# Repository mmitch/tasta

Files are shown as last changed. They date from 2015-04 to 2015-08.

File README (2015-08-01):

tasta - small USB keyboard
Copyright (C) 2015 by  Christian Garbs <mitch@cgarbs.de>
Licensed under GNU GPL v2 or v3

Project homepage:
-----------------
https://github.com/mmitch/tasta

Description:
------------
tasta a small USB HID keyboard with just two keys and the
corresponding code to program the ATtiny85.  This is my first
microcontroller/PCB project.  I developed it as a foot switch for
push-to-talk in TeamSpeak as I don't have any spare keys (or fingers)
during gaming.  I fiddled with this on and off over the course of two
years, now it should be ready to do something.

Hardware:
---------
The curcuit schematics and PCB layout are available in different
formats in the 'circuit' subdirectory.  They were created with KiCad,
so it's propably best to edit them with KiCad, too, if the need
arises.

There are some optional components in the layout:

 - You can omit the LED and R5 if you don't need it.

 - You can omit either key switch or the K1 connector as needed.  K1
   is used to provide key input from 'offboard', like the foot switch
   I use.

 - R4 is propably not needed.  In fact, I have never included it,
   neither in test runs nor in the final PCB.  But the docs say you
   should pull up your reset pin, so the possibility to insert the
   resistor is there if you should ever need it.  (I did include it
   'just in case' so I would not have to throw away the first PCB
   batch.)

Software:
---------
To build the software, go to the 'source' directory and just run
'make'.  A normal Atmel development environment is needed, so install
'avr-gcc' and friends.

To configure the software (to choose your own keybindings), edit
'main.c' and look for these two sections:
 - EDIT BELOW FOR YOUR OWN LED CONFIGURATION
 - EDIT BELOW FOR YOUR OWN KEY CONFIGURATION

Default configuration is:
 - key 1 = GUI left (Windows key -> modifier only)
 - key 2 = return
 - the LED is on if key 1 || key 2 is pressed

To flash the code to your ATtiny85, run 'make flash'.  The default
configuration uses avrdude with a 'usbasp' compatible programmer.
Edit the AVRDUDE_* variables in 'Makefile.orig' to change this.

Credits:
--------
PCB and basic code are heavily influenced from other projects, as you
can see in the repository log.  Other parts were rewritten, redone and
rearranged by myself.  Credits where credits are due:

 * VUSB project for USB on Atmel microcontrollers:
   http://www.obdev.at/vusb/

 * VUSB HIDKeys example project for a USB HID compliant keyboard:
   https://www.obdev.at/products/vusb/hidkeys.html

 * Information on running a VUSB project without a crystal taken from
   flipwork's 1-Key-keyboard:
   http://blog.flipwork.nl/?x=entry:entry081009-142605

 * better OSCCAL calibration routine taken from here:
   http://codeandlife.com/2012/02/22/v-usb-with-attiny45-attiny85-without-a-crystal/

 * My PCBs were printed at Hackvana.  I've never done this before and
   everything went right on the first try (well, on the second, I had
   one misnamed file in the rev_0x0002 export, but that's my fault):
   http://www.hackvana.com/

Licensing:
----------
The VUSB example projects are licensed under GPL 2 or GPL 3 (you can
choose).  The imported code from flipwork and codeandlife is based on
VUSB projects as well (HIDKeys/EasyLogger), so they're GPL 2/3, too.
My project thus is also GPL 2/3 and everybody's happy.

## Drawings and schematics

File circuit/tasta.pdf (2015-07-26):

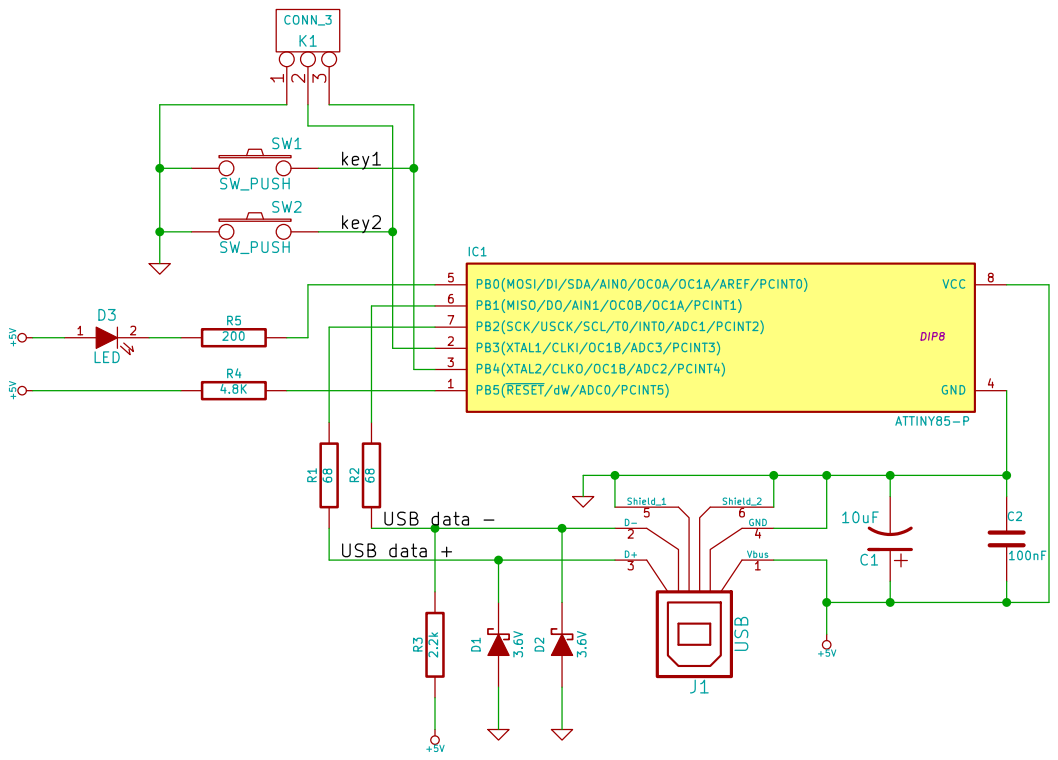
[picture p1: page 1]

https://github.com/mmitch/tasta
http://www.cgarbs.de/
Christian Garbs <mitch@cgarbs.de>
Id: 1/1 Title: tasta File: tasta.sch Sheet: /

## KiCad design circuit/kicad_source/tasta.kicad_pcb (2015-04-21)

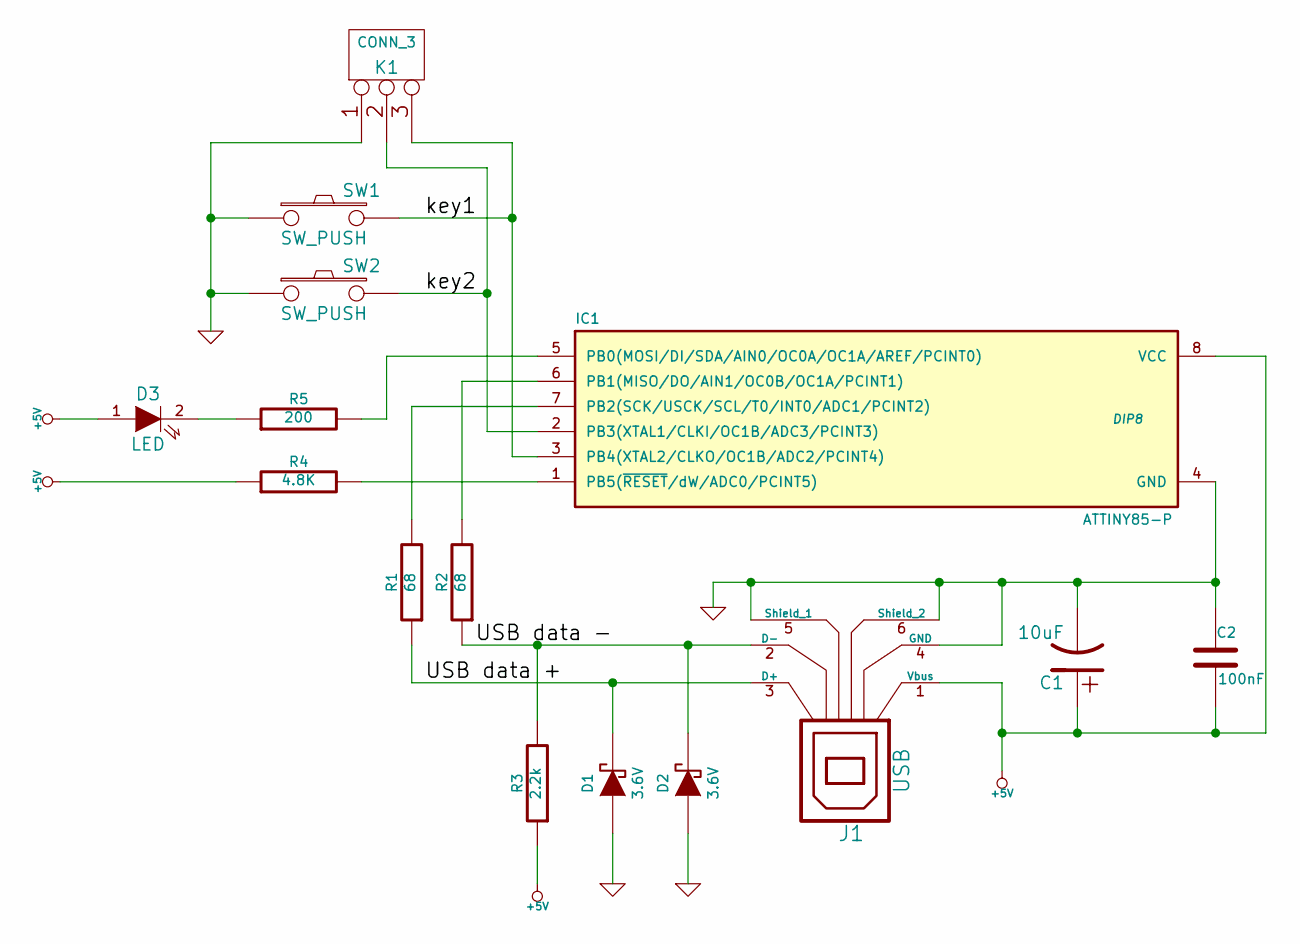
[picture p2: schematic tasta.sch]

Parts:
C1: 10uF
C2: 100nF
D1, D2: 3.6V
D3: LED
IC1: ATTINY85-P; DIP8
J1: USB
K1: CONN_3
R1, R2: 68
R3: 2.2k
R4: 4.8K
R5: 200
SW1, SW2: SW_PUSH

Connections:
+5V: C1.1, C2.2, D3.1 (A), IC1.8 (VCC), J1.1 (Vbus), R3.1, R4.1
/USB data +: D1.2 (K), J1.3 (D+), R1.1
/USB data -: D2.2 (K), J1.2 (D-), R2.1, R3.2
/key1: IC1.3 (PB4(XTAL2/CLKO/OC1B/ADC2/PCINT4)), K1.3, SW1.2
/key2: IC1.2 (PB3(XTAL1/CLKI/OC1B/ADC3/PCINT3)), K1.2 (PM), SW2.2
GND: C1.2, C2.1, D1.1 (A), D2.1 (A), IC1.4 (GND), J1.4 (GND), J1.5 (Shield_1), J1.6 (Shield_2), K1.1, SW1.1, SW2.1
unnamed: IC1.6 (PB1(MISO/DO/AIN1/OC0B/OC1A/PCINT1)), R2.2
unnamed: D3.2 (K), R5.1
unnamed: IC1.7 (PB2(SCK/USCK/SCL/T0/INT0/ADC1/PCINT2)), R1.2
unnamed: IC1.5 (PB0(MOSI/DI/SDA/AIN0/OC0A/OC1A/AREF/PCI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), R5.2
unnamed: IC1.1 (PB5(~RESET~/dW/ADC0/PCINT5)), R4.2

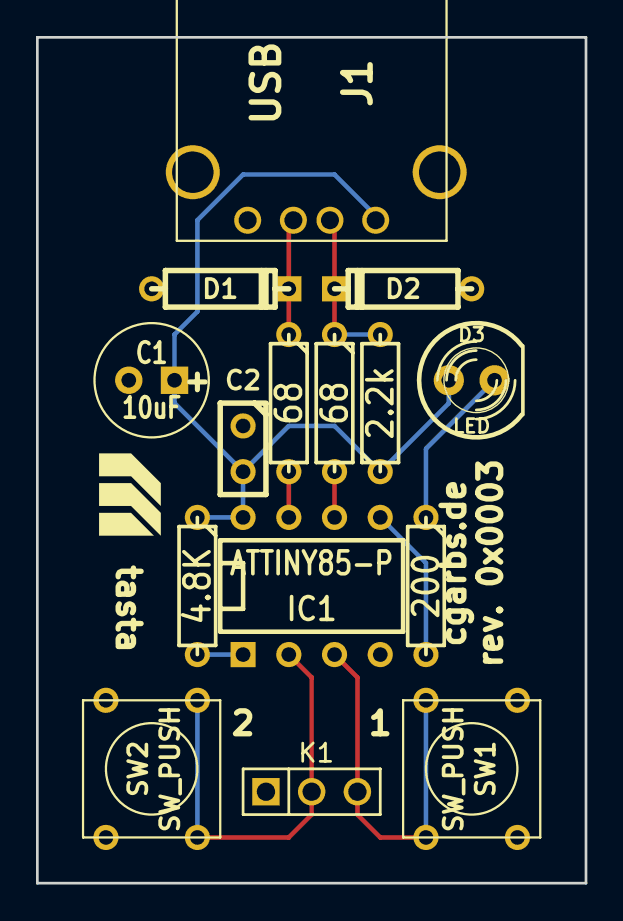
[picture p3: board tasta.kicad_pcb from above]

Board: 2 copper layers, 30.5 x 47.0 mm, 15 parts (0 on the bottom side), 11 nets.

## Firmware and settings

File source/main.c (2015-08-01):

/*
 * tasta - simple USB keyboard for ATtiny85
 * Copyright (C) 2015 Christian Garbs <mitch@cgarbs.de>
 * Licensed under GNU GPL v2 or v3
 *
 * based upon HIDKeys example from V-USB/obdev:
 *
 *
 * Name: main.c
 * Project: HID-Test
 * Author: Christian Starkjohann
 * Creation Date: 2006-02-02
 * Copyright: (c) 2006 by OBJECTIVE DEVELOPMENT Software GmbH
 * License: GNU GPL v2  (or GNU GPL v3 as the complete License.txt says)
 * Homepage: http://www.obdev.at/vusb/
 * Source: https://www.obdev.at/downloads/vusb/HIDKeys.2012-12-08.tar.gz
 */

#include <avr/eeprom.h>
#include <avr/interrupt.h>
#include <avr/io.h>
#include <avr/pgmspace.h>
#include <avr/wdt.h>
#include <util/delay.h>
#include <stdlib.h>

#include "usbdrv/usbdrv.h"

/* ----------------------- hardware I/O abstraction ------------------------ */

/* pin assignments:
PB0	LED (output, but acts as a sink: deactivate pullup = LED on)
PB1     USB data -
PB2     USB data +
PB3     button 2
PB4     button 1
PB5     reset (in hardware; unused here)
*/

#define BUTTON_PORT     PORTB       /* PORTx - register for buttons (pullups) */
#define BUTTON_PIN      PINB        /* PINx  - register for buttons (input state) */
#define LED_PORT        PORTB       /* PORTx - register for LED (pullups) */
#define LED_DDR         DDRB        /* DDRx  - register for LED (set to output) */

#define BUTTON1_BIT     PB4         /* bit for button 1 in button register */
#define BUTTON2_BIT     PB3         /* bit for button 2 in button register */
#define LED_BIT         PB0         /* bit for LED in LED register */

#define KEY1            (1 << 0)    /* bitmask for key 1 */
#define KEY2            (1 << 1)    /* bitmask for key 2 */

/* LED is controlled via pull-up: no pullup = acts as sink = LED on */
#define LED_ON      (LED_PORT &= ~_BV(LED_BIT))
#define LED_OFF     (LED_PORT |=  _BV(LED_BIT))

#define GET_BIT(pin,bit) (pin & _BV(bit))


static void hardwareInit(void)
{
	uchar i;
	uchar calibrationValue;

	calibrationValue = eeprom_read_byte(0); /* calibration value from last time */
	if (calibrationValue != 0xff)
	{
		OSCCAL = calibrationValue;
	}

	usbInit();
	usbDeviceDisconnect();  /* enforce re-enumeration, do this while interrupts are disabled! */
	i = 0;
	while(--i){             /* fake USB disconnect for > 250 ms */
		wdt_reset();
		_delay_ms(1);
	}
	usbDeviceConnect();

	wdt_enable(WDTO_1S);

	/* activate pull-ups for the buttons */
	BUTTON_PORT |= _BV(BUTTON1_BIT) | _BV(BUTTON2_BIT);

	/* initialize LED output */
	LED_DDR |= _BV(LED_BIT);
	LED_ON;

	/* select clock: 16.5M/1k -> overflow rate = 16.5M/256k = 62.94 Hz (~11ms) */
	TCCR1 = 0x0b;
}

/* USB IDLE is counted in 4ms - how many are there in one timer overflow (~11ms)? */
#define OVERFLOWS_4MS 3
/* TODO: this is slightly too much, would 2 be better? */

/* ------------------------------------------------------------------------- */

#define NUM_KEYS 2

/* The following function returns an index for the first key pressed. It
 * returns 0 if no key is pressed.
 *
 * TODO: make both keys work independently from each other (don't let button 1
 *       'overshadow' button 2)
 */
static uchar keyPressed(void)
{
	uchar keystate = 0;

	/* 
	 * look out (I _always_ stumble over this):
	 * as the buttons short to GND on closing, the pin value is reversed:
	 * button bit = 0 -> button is pressed
	 * button bit = 1 -> button is not pressed (pull-up active)
	 */
	if (GET_BIT(BUTTON_PIN, BUTTON1_BIT) == 0)
	{
		keystate |= KEY1;
	}
	if (GET_BIT(BUTTON_PIN, BUTTON2_BIT) == 0)
	{
		keystate |= KEY2;
	}



	/*********************************************/
	/* EDIT BELOW FOR YOUR OWN LED CONFIGURATION */

	if (keystate == 0)
	{
		LED_OFF;
	}
	else
	{
		LED_ON;
	}

	/* EDIT ABOVE FOR YOUR OWN LED CONFIGURATION */
	/*********************************************/



	return keystate;
}

/* ------------------------------------------------------------------------- */
/* ----------------------------- USB interface ----------------------------- */
/* ------------------------------------------------------------------------- */

static uchar reportBuffer[3];    /* buffer for HID reports */
static uchar idleRate;           /* in 4 ms units */

#define KEYS_IN_REPORT 2   /* modifier does not count, only slots for real keys (the REPORT_COUNT of the second INPUT below) */

const PROGMEM char usbHidReportDescriptor[35] = {   /* USB report descriptor */
	0x05, 0x01,                    // USAGE_PAGE (Generic Desktop)
	0x09, 0x06,                    // USAGE (Keyboard)
	0xa1, 0x01,                    // COLLECTION (Application)
	0x05, 0x07,                    //   USAGE_PAGE (Keyboard)
	0x19, 0xe0,                    //   USAGE_MINIMUM (Keyboard LeftControl)
	0x29, 0xe7,                    //   USAGE_MAXIMUM (Keyboard Right GUI)
	0x15, 0x00,                    //   LOGICAL_MINIMUM (0)
	0x25, 0x01,                    //   LOGICAL_MAXIMUM (1)
	0x75, 0x01,                    //   REPORT_SIZE (1)
	0x95, 0x08,                    //   REPORT_COUNT (8)
	0x81, 0x02,                    //   INPUT (Data,Var,Abs)
	0x95, 0x02,                    //   REPORT_COUNT (2)
	0x75, 0x08,                    //   REPORT_SIZE (8)
	0x25, 0x65,                    //   LOGICAL_MAXIMUM (101)
	0x19, 0x00,                    //   USAGE_MINIMUM (Reserved (no event indicated))
	0x29, 0x65,                    //   USAGE_MAXIMUM (Keyboard Application)
	0x81, 0x00,                    //   INPUT (Data,Ary,Abs)
	0xc0                           // END_COLLECTION
};
/* We use a simplifed keyboard report descriptor which does not support the
 * boot protocol. We don't allow setting status LEDs and we only allow one
 * simultaneous key press (except modifiers). We can therefore use short
 * 2 byte input reports.
 * The report descriptor has been created with usb.org's "HID Descriptor Tool"
 * which can be downloaded from http://www.usb.org/developers/hidpage/.
 * Redundant entries (such as LOGICAL_MINIMUM and USAGE_PAGE) have been omitted
 * for the second INPUT item.
 */

/* Keyboard usage values, see usb.org's HID-usage-tables document, chapter
 * 10 Keyboard/Keypad Page for more codes.
 */
#define MOD_CONTROL_LEFT    (1<<0)
#define MOD_SHIFT_LEFT      (1<<1)
#define MOD_ALT_LEFT        (1<<2)
#define MOD_GUI_LEFT        (1<<3)  /* "Windows" key */
#define MOD_CONTROL_RIGHT   (1<<4)
#define MOD_SHIFT_RIGHT     (1<<5)
#define MOD_ALT_RIGHT       (1<<6)
#define MOD_GUI_RIGHT       (1<<7)  /* "Windows" key */

#define KEY_ERROR_ROLLOVER  1       /* error condition "too many keys at once pressed" */

#define KEY_A       4
#define KEY_B       5
#define KEY_C       6
#define KEY_D       7
#define KEY_E       8
#define KEY_F       9
#define KEY_G       10
#define KEY_H       11
#define KEY_I       12
#define KEY_J       13
#define KEY_K       14
#define KEY_L       15
#define KEY_M       16
#define KEY_N       17
#define KEY_O       18
#define KEY_P       19
#define KEY_Q       20
#define KEY_R       21
#define KEY_S       22
#define KEY_T       23
#define KEY_U       24
#define KEY_V       25
#define KEY_W       26
#define KEY_X       27
#define KEY_Y       28
#define KEY_Z       29
#define KEY_1       30
#define KEY_2       31
#define KEY_3       32
#define KEY_4       33
#define KEY_5       34
#define KEY_6       35
#define KEY_7       36
#define KEY_8       37
#define KEY_9       38
#define KEY_0       39

#define KEY_ENTER   40

#define KEY_F1      58
#define KEY_F2      59
#define KEY_F3      60
#define KEY_F4      61
#define KEY_F5      62
#define KEY_F6      63
#define KEY_F7      64
#define KEY_F8      65
#define KEY_F9      66
#define KEY_F10     67
#define KEY_F11     68
#define KEY_F12     69

static void buildReport(uchar key)
{
	uchar modifiers = 0;
	uchar keypos = 0;

	/*********************************************/
	/* EDIT BELOW FOR YOUR OWN KEY CONFIGURATION */

	/* Key test examples follow:

	if (key & KEY1)
	{
		// one modifier, no keys
		modifiers |= MOD_GUI_LEFT;
	}

	if (key & KEY2)
	{
		// *two* keys, no modifiers
		reportBuffer[++keypos] = KEY_A;
		reportBuffer[++keypos] = KEY_B;
	}

	*/

	if (key & KEY1)
	{
		// one modifier, no keys
		modifiers |= MOD_GUI_LEFT;
	}

	if (key & KEY2)
	{
		// one key, no modifiers
		reportBuffer[++keypos] = KEY_ENTER;
	}

	/* EDIT ABOVE FOR YOUR OWN KEY CONFIGURATION */
	/*********************************************/



	reportBuffer[0] = modifiers;
	
	if (keypos > KEYS_IN_REPORT)
	{
		/* Keyboard ErrorRollOver condition (too many keys pressed) */
		keypos = 0;
		while (keypos < KEYS_IN_REPORT)
		{
			reportBuffer[++keypos] = KEY_ERROR_ROLLOVER;
		}
	}
	else
	{
		/* fill remaining/unused keys in report with zero */
		while (keypos < KEYS_IN_REPORT)
		{
			reportBuffer[++keypos] = 0;
		}
	}
}

uchar usbFunctionSetup(uchar data[8])
{
	usbRequest_t *rq = (void *)data;

	usbMsgPtr = reportBuffer;
	if ((rq->bmRequestType & USBRQ_TYPE_MASK) == USBRQ_TYPE_CLASS) /* class request type */
	{
		if (rq->bRequest == USBRQ_HID_GET_REPORT) /* wValue: ReportType (highbyte), ReportID (lowbyte) */
		{
			/* we only have one report type, so don't look at wValue */
			buildReport(keyPressed());
			return sizeof(reportBuffer);
		}
		else if(rq->bRequest == USBRQ_HID_GET_IDLE)
		{
			usbMsgPtr = &idleRate;
			return 1;
		}
		else if(rq->bRequest == USBRQ_HID_SET_IDLE)
		{
			idleRate = rq->wValue.bytes[1];
		}
	}
	else
	{
		/* no vendor specific requests implemented */
	}
	return 0;
}

/* ------------------------------------------------------------------------- */
/* ------------------------ Oscillator Calibration ------------------------- */
/* ------------------------------------------------------------------------- */

/* Calibrate the RC oscillator to 8.25 MHz. The core clock of 16.5 MHz is
 * derived from the 66 MHz peripheral clock by dividing. Our timing reference
 * is the Start Of Frame signal (a single SE0 bit) available immediately after
 * a USB RESET.
 */
static void calibrateOscillator(void)
{
	int frameLength, targetLength = (unsigned)(1499 * (double)F_CPU / 10.5e6 + 0.5);
	int bestDeviation = 9999;
	uchar trialCal, bestCal, step, region;

	/* do a binary search in regions 0-127 and 128-255 to get optimum OSCCAL */
	for (region = 0; region <= 1; region++)
	{
		frameLength = 0;
		trialCal = (region == 0) ? 0 : 128;
        
		for (step = 64; step > 0; step >>= 1)
		{
			if (frameLength < targetLength) /* true for initial iteration */
			{
				trialCal += step; /* frequency too low */
			}
			else
			{
				trialCal -= step; /* frequency too high */
			}
                
			OSCCAL = trialCal;
			frameLength = usbMeasureFrameLength();
			
			if (abs(frameLength-targetLength) < bestDeviation)
			{
				bestCal = trialCal; /* new optimum found */
				bestDeviation = abs(frameLength -targetLength);
			}
		}
	}

	OSCCAL = bestCal;
}

void usbEventResetReady(void)
{
	calibrateOscillator();
	eeprom_write_byte(0, OSCCAL); /* store the calibrated value in EEPROM */
}

/* ------------------------------------------------------------------------- */

int main(void)
{
	uchar key, lastKey = 0, keyDidChange = 0;
	uchar idleCounter = 0;

	hardwareInit();
	sei();
	for (;;) /* main event loop */
	{
		wdt_reset();
		usbPoll();
		key = keyPressed();
		if (lastKey != key)
		{
			lastKey = key;
			keyDidChange = 1;
		}
		if (TIFR & (1<<TOV0)) /* ~63 ms timer */
		{
			TIFR = 1<<TOV0; /* clear overflow */
			if (idleRate != 0)
			{
				if (idleCounter >= OVERFLOWS_4MS)
				{
					idleCounter -= OVERFLOWS_4MS;
				}
				else
				{
					/* USB HID poll timer reached
					 * send current state regardless of real key change */
					idleCounter = idleRate;
					keyDidChange = 1;
				}
			}
		}
		if (keyDidChange && usbInterruptIsReady())
		{
			keyDidChange = 0;
			/* use last key and not current key status in order to avoid lost
			   changes in key status. */
			buildReport(lastKey);
			usbSetInterrupt(reportBuffer, sizeof(reportBuffer));
		}
	}
	return 0;
}

/* ------------------------------------------------------------------------- */

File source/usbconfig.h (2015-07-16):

/* Name: usbconfig.h
 * Project: AVR USB driver
 * Author: Christian Starkjohann
 * Creation Date: 2005-04-01
 * Tabsize: 4
 * Copyright: (c) 2005 by OBJECTIVE DEVELOPMENT Software GmbH
 * License: GNU GPL v2 (see License.txt) or proprietary (CommercialLicense.txt)
 * This Revision: $Id$
 */

#ifndef __usbconfig_h_included__
#define __usbconfig_h_included__

/* ---------------------------- Hardware Config ---------------------------- */

#define USB_CFG_IOPORTNAME      B
/* This is the port where the USB bus is connected. When you configure it to
 * "B", the registers PORTB, PINB and DDRB will be used.
 */
#define USB_CFG_DMINUS_BIT      1
/* This is the bit number in USB_CFG_IOPORT where the USB D- line is connected.
 * This may be any bit in the port.
 */
#define USB_CFG_DPLUS_BIT       2
/* This is the bit number in USB_CFG_IOPORT where the USB D+ line is connected.
 * This may be any bit in the port. Please note that D+ must also be connected
 * to interrupt pin INT0!
 */
#define USB_CFG_CLOCK_KHZ       16500
/* Clock rate of the AVR in MHz. Legal values are 12000, 16000 or 16500.
 * The 16.5 MHz version of the code requires no crystal, it tolerates +/- 1%
 * deviation from the nominal frequency. All other rates require a precision
 * of 2000 ppm and thus a crystal!
 * Default if not specified: 12 MHz
 */

/* ----------------------- Optional Hardware Config ------------------------ */

/* #define USB_CFG_PULLUP_IOPORTNAME   D */
/* If you connect the 1.5k pullup resistor from D- to a port pin instead of
 * V+, you can connect and disconnect the device from firmware by calling
 * the macros usbDeviceConnect() and usbDeviceDisconnect() (see usbdrv.h).
 * This constant defines the port on which the pullup resistor is connected.
 */
/* #define USB_CFG_PULLUP_BIT          4 */
/* This constant defines the bit number in USB_CFG_PULLUP_IOPORT (defined
 * above) where the 1.5k pullup resistor is connected. See description
 * above for details.
 */

/* --------------------------- Functional Range ---------------------------- */

#define USB_CFG_HAVE_INTRIN_ENDPOINT    1
/* Define this to 1 if you want to compile a version with two endpoints: The
 * default control endpoint 0 and an interrupt-in endpoint 1.
 */
#define USB_CFG_HAVE_INTRIN_ENDPOINT3   0
/* Define this to 1 if you want to compile a version with three endpoints: The
 * default control endpoint 0, an interrupt-in endpoint 1 and an interrupt-in
 * endpoint 3. You must also enable endpoint 1 above.
 */
#define USB_CFG_IMPLEMENT_HALT          0
/* Define this to 1 if you also want to implement the ENDPOINT_HALT feature
 * for endpoint 1 (interrupt endpoint). Although you may not need this feature,
 * it is required by the standard. We have made it a config option because it
 * bloats the code considerably.
 */
#define USB_CFG_INTR_POLL_INTERVAL      10
/* If you compile a version with endpoint 1 (interrupt-in), this is the poll
 * interval. The value is in milliseconds and must not be less than 10 ms for
 * low speed devices.
 */
#define USB_CFG_IS_SELF_POWERED         0
/* Define this to 1 if the device has its own power supply. Set it to 0 if the
 * device is powered from the USB bus.
 */
#define USB_CFG_MAX_BUS_POWER           50
/* Set this variable to the maximum USB bus power consumption of your device.
 * The value is in milliamperes. [It will be divided by two since USB
 * communicates power requirements in units of 2 mA.]
 */
#define USB_CFG_IMPLEMENT_FN_WRITE      0
/* Set this to 1 if you want usbFunctionWrite() to be called for control-out
 * transfers. Set it to 0 if you don't need it and want to save a couple of
 * bytes.
 */
#define USB_CFG_IMPLEMENT_FN_READ       0
/* Set this to 1 if you need to send control replies which are generated
 * "on the fly" when usbFunctionRead() is called. If you only want to send
 * data from a static buffer, set it to 0 and return the data from
 * usbFunctionSetup(). This saves a couple of bytes.
 */
#define USB_CFG_IMPLEMENT_FN_WRITEOUT   0
/* Define this to 1 if you want to use interrupt-out (or bulk out) endpoint 1.
 * You must implement the function usbFunctionWriteOut() which receives all
 * interrupt/bulk data sent to endpoint 1.
 */
#define USB_CFG_HAVE_FLOWCONTROL        0
/* Define this to 1 if you want flowcontrol over USB data. See the definition
 * of the macros usbDisableAllRequests() and usbEnableAllRequests() in
 * usbdrv.h.
 */
#ifndef __ASSEMBLER__
extern void usbEventResetReady(void);
#endif
#define USB_RESET_HOOK(isReset)             if(!isReset){usbEventResetReady();}
/* This macro is a hook if you need to know when an USB RESET occurs. It has
 * one parameter which distinguishes between the start of RESET state and its
 * end.
 */
#define USB_CFG_HAVE_MEASURE_FRAME_LENGTH   1
/* define this macro to 1 if you want the function usbMeasureFrameLength()
 * compiled in. This function can be used to calibrate the AVR's RC oscillator.
 */
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

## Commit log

2015-03-16 initial schema and pcb import
    [tasta.dsn, tasta.kicad_pcb, tasta.sch]
2015-03-26 PCB layout: set stroke width of LED labels to 6mil
    [tasta.kicad_pcb]
2015-03-26 remove unneeded and out of date autorouter file
    [tasta.dsn]
2015-03-26 prepare checkin of created Gerber files
    Gerber export via KiCad scripting might be possible, but for now
    just stick with a manual export
2015-03-26 fix renaming of files in KiCad export
    The Gerber mask files were missing and their filenames were confused
    with the copper layers'.
2015-03-26 add logo to PCB
    [tasta.kicad_pcb]
2015-03-26 checkin exported Gerber files
    [tasta.back.gbl, tasta.backmask.gbs, tasta.backsilk.gbo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]
2015-03-27 update logo on PCB
    handcrafted logo is better than Bitmap2Component conversion
    [tasta.kicad_pcb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]
2015-03-27 kicad_export: add check for revision on PCB before creating the ZIP
2015-04-21 fix frontsilk extension
    .gto, not .gbo
    [tasta.frontsilk.gto]
2015-04-21 update revision after frontsilk extension change
    [tasta.kicad_pcb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]
2015-07-16 import V-USB HIDKeys example project
    License.txt says it's GPL 2/3, so that's ok.
    Thanks go out to objective development for providing V-USB:
    http://www.obdev.at/vusb/
    The imported code was taken from here:
    https://www.obdev.at/downloads/vusb/HIDKeys.2012-12-08.tar.gz
    [hidkeys.sch]
2015-07-16 remove unneeded HIDKeys files
    [hidkeys.sch]
2015-07-16 switch to tasta hardware and define own keys
2015-07-16 more adjustments to tasta project
    - initialize the correct ports
    - switch timer timings to 16.5 MHz
    - do USB reset via device disconnect/reconnect
    This idea is taken from the flipwork 1-Key-Keyboard
    project at http://blog.flipwork.nl/?x=entry:entry081009-142605
    Source: http://blog.flipwork.nl/fp-content/attachs/1_key_keyboard.zip
    [main.c]
2015-07-16 add timer calibration
    As tasta runs without external crystals on the internal clock of the
    ATtiny85, the timer has to be calibrated.
    This routine is again taken from the flipwork 1-Key-Keyboard
    The code distinguishes between USB resets (timing is recalculated and
    stored in EEPROM) and mere watchdog resets (existing timing is read
    from EEPROM). That's why hardware_init() works does USB disconnect +
    USB connect rather than a full USB reset like the original V-USB
    example code.
    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
    [main.c]
2015-07-16 switch OSCCAL calibration routine
    Replace 1-Key-Keyboard's V-USB-based calibration routine by the one
    from here:
    http://codeandlife.com/2012/02/22/v-usb-with-attiny45-attiny85-without-a-crystal/
    This searches both regions 0..127 and 128..255, to which the original
    VUSB code said "this might be a good idea, so go and write your own
    calibration routine".
    [main.c]
2015-07-16 switch to my own build system (read: different Makefile)
    see top of Makefile.orig for where this originates from...
2015-07-16 fix LED handling
    LED ON: output port has pullup removed and acts as a sink
    LED OFF: output port is pulled up, LED has +5V on both sides
    [main.c]
2015-07-26 rewrite handling of keypresses
    - expand USB HID report to allow two keys at once
    - read multiple keypresses simultaneously (bit field)
    - dynamically create USB report (variable length/key count)
    Also mark code sections for user-defined keypress and LED handling.
2015-07-26 fix keypress events
    actually send the report that has been assembled :-)
    [main.c]
2015-07-26 fix keypress detection
    d'oh: buttons are reversed - as always :-/
    [main.c]
2015-07-26 fix errors in buildReport()
    [main.c]
2015-07-26 add project info to schematics
    [tasta.sch]
2015-07-26 add schematics PDF export to repository
    No need to install KiCad to see what this is all about.
2015-07-26 check revision on schematics on export
    Also check the PDF, this needs the pdftotext utility.
    This should ensure that everything is up-to-date after any changes.

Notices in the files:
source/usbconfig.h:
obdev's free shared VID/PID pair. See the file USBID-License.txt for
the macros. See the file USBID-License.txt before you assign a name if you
